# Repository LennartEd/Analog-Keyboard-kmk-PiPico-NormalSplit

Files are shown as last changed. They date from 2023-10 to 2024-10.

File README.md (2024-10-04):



# Analog-Keyboard-kmk-PiPico-NormalSplit
This is a fully analog keyboard using magnetic keys and hall sensors. I'm using a RP2040 but since it is KMK (circuitpython) based it should be compatible with other boards. I build a split keyboard, but any type form factor should work. 
This is my first experience with circuitpython so code might me wonky.

#TO-DO
- [ ] automatic callibration
- [ ] support all types of multiplexers (not just 16:1)
- [ ] fix mouse wheel only pressing every second turn

# PCB
**!DONT USE THE PCB PROVIDED!**
The PCB provided has some flaws that make it hard to work with.
**I would recommend making your own PCB and using mine as a template.**
In the future i might create v2 template that fixes the flaws.
Also as LCSC didn't have the LEDs in stock, I build mine without them. So there is no guaranty that I did the LED wiring correctly. I did however test the code with the onboard led of the RP2040, so the code should work.

### Flaws with v1
- Horizontal encoder has the wrong footprint (gnd is not in the middle)
- dont solder MCU daughter board onto PCB directly
- bigger pads for hand soldering
- more mounting holes
- if possible 2 layer PCB for cost saving

### Parts
|Description | Part | LCSC |
|:---| --- |:---|
| Hall sensor| HX6659ISO-B | C495742		|
| Multiplexer| CD74HC4067M96 | C496123		|
| TRRS jack  | PJ-3220-5A	 | C707251		|
| MCU		 | Waveshare RP2040-zero| --	|
| ~~Capacitor 100uF~~| ~~GRM21BR60J107ME15L~~| ~~C141660~~|
|(LED) |sk6812 mini-e  | C5149201 |

### Part notes
**Hall sensor:** 

**Multiplexer:** Currently any 16to1 Multiplexer should work (giving you 64 keys). If you are not hand soldering i recommend choosing a smaller sized one. Larger (32to1) should also work.

**MCU:** Any circuitpython compatible board should work. You just have to change the footprint on the PCB (which you should do anyway. See "Flaws with v1"

**TRRS jack:** 

**Capacitor:** Capacitors are not strictly necessary but improve resolution. ~~I tried a few and found that 100uF worked the best.~~ Use different sensor filters

#### How it works
The position of the magnet in the switch is red by the hall-effect sensor. Because the pi-pico only has 4 ADCs we need multiplexers to cycle between the sensors. 

# Code
To install the code connect your board and install circuitpython. Then copy the content of the "code" folder into the board. For editing the code you can use Thonny or any text editor.

### pins
To make life easier by not having to use "board.GP.." all the time, create (if not already present) a python file in lib/kmk/quickpin. Then add all the pins (see the other files for reference).
Now when imported with 
~~~
from kmk.quickpin.<boardTypeFolder>.<boardPins> import pinout as pins
~~~
into other files you can just use "pins[x]" to reference pins

### kb.py:
Here you define most variables for you specific board.

### Code.py

### hallCali.py

### analogio.py

# Case

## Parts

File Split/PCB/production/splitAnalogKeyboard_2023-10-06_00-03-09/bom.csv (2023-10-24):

Designator | Footprint | Quantity | Value | LCSC Part #
_22, _21, _20, _19, _18, _17, _16, _15, _14, _13, _12, _11, _10, _9, _8, _7, _6, _5, _4, _3, _2, | 634f0b0a-7a0d-49f3-8c6d-20ae2e3a1092 | 22
CN1 | AUDIO-TH_HOOYA_PJ-322 | 1 | PJ-322 | C2939185
H1_2, H1, H10_2, H10, H11_2, H11, H12_2, H12, H13_2, H13, H14_2, H14, H15_2, H15, H16_2, H16, H17_2, H17, H18_2, H18, H19_2, H19, H2_2, H2, H20_2, H20, H21_2, H21, H22_2, H22, H3_2, H3, H4_2, H4, H5_2, H5, H6_2, H6, H7_2, H7, H8_2, H8, H9_2, H9 | SOT-23-3_L2.9-W1.6-P1.90-LS2.8-BR | 44 | HX6659ISO-B | C495742
LED1_2, LED1, LED10_2, LED10, LED11_2, LED11, LED12_2, LED12, LED13_2, LED13, LED14_2, LED14, LED15_2, LED15, LED16_2, LED16, LED17_2, LED17, LED18_2, LED18, LED19_2, LED19, LED2_2, LED2, LED20_2, LED20, LED21_2, LED21, LED22_2, LED22, LED3_2, LED3, LED4_2, LED4, LED5_2, LED5, LED6_2, LED6, LED7_2, LED7, LED8_2, LED8, LED9_2, LED9 | LED-SMD_4P-L3.2-W2.8_SK6812MINI-EA | 44 | SK6812MINI-EA | C5378731
SW1, SW3 | MouseEncoder | 2 | ~
SW2 | SW-TH_EC11NXXXX | 1 | EC11N1520401 | C470703
U1_2, U1, U2_2, U2 | SOIC-24_L15.4-W7.5-P1.27-LS10.3-BL | 4 | CD74HC4067M96 | C496123
U3_2, U3 | RP2040-Zero-outer | 2 | RP2040-Zero

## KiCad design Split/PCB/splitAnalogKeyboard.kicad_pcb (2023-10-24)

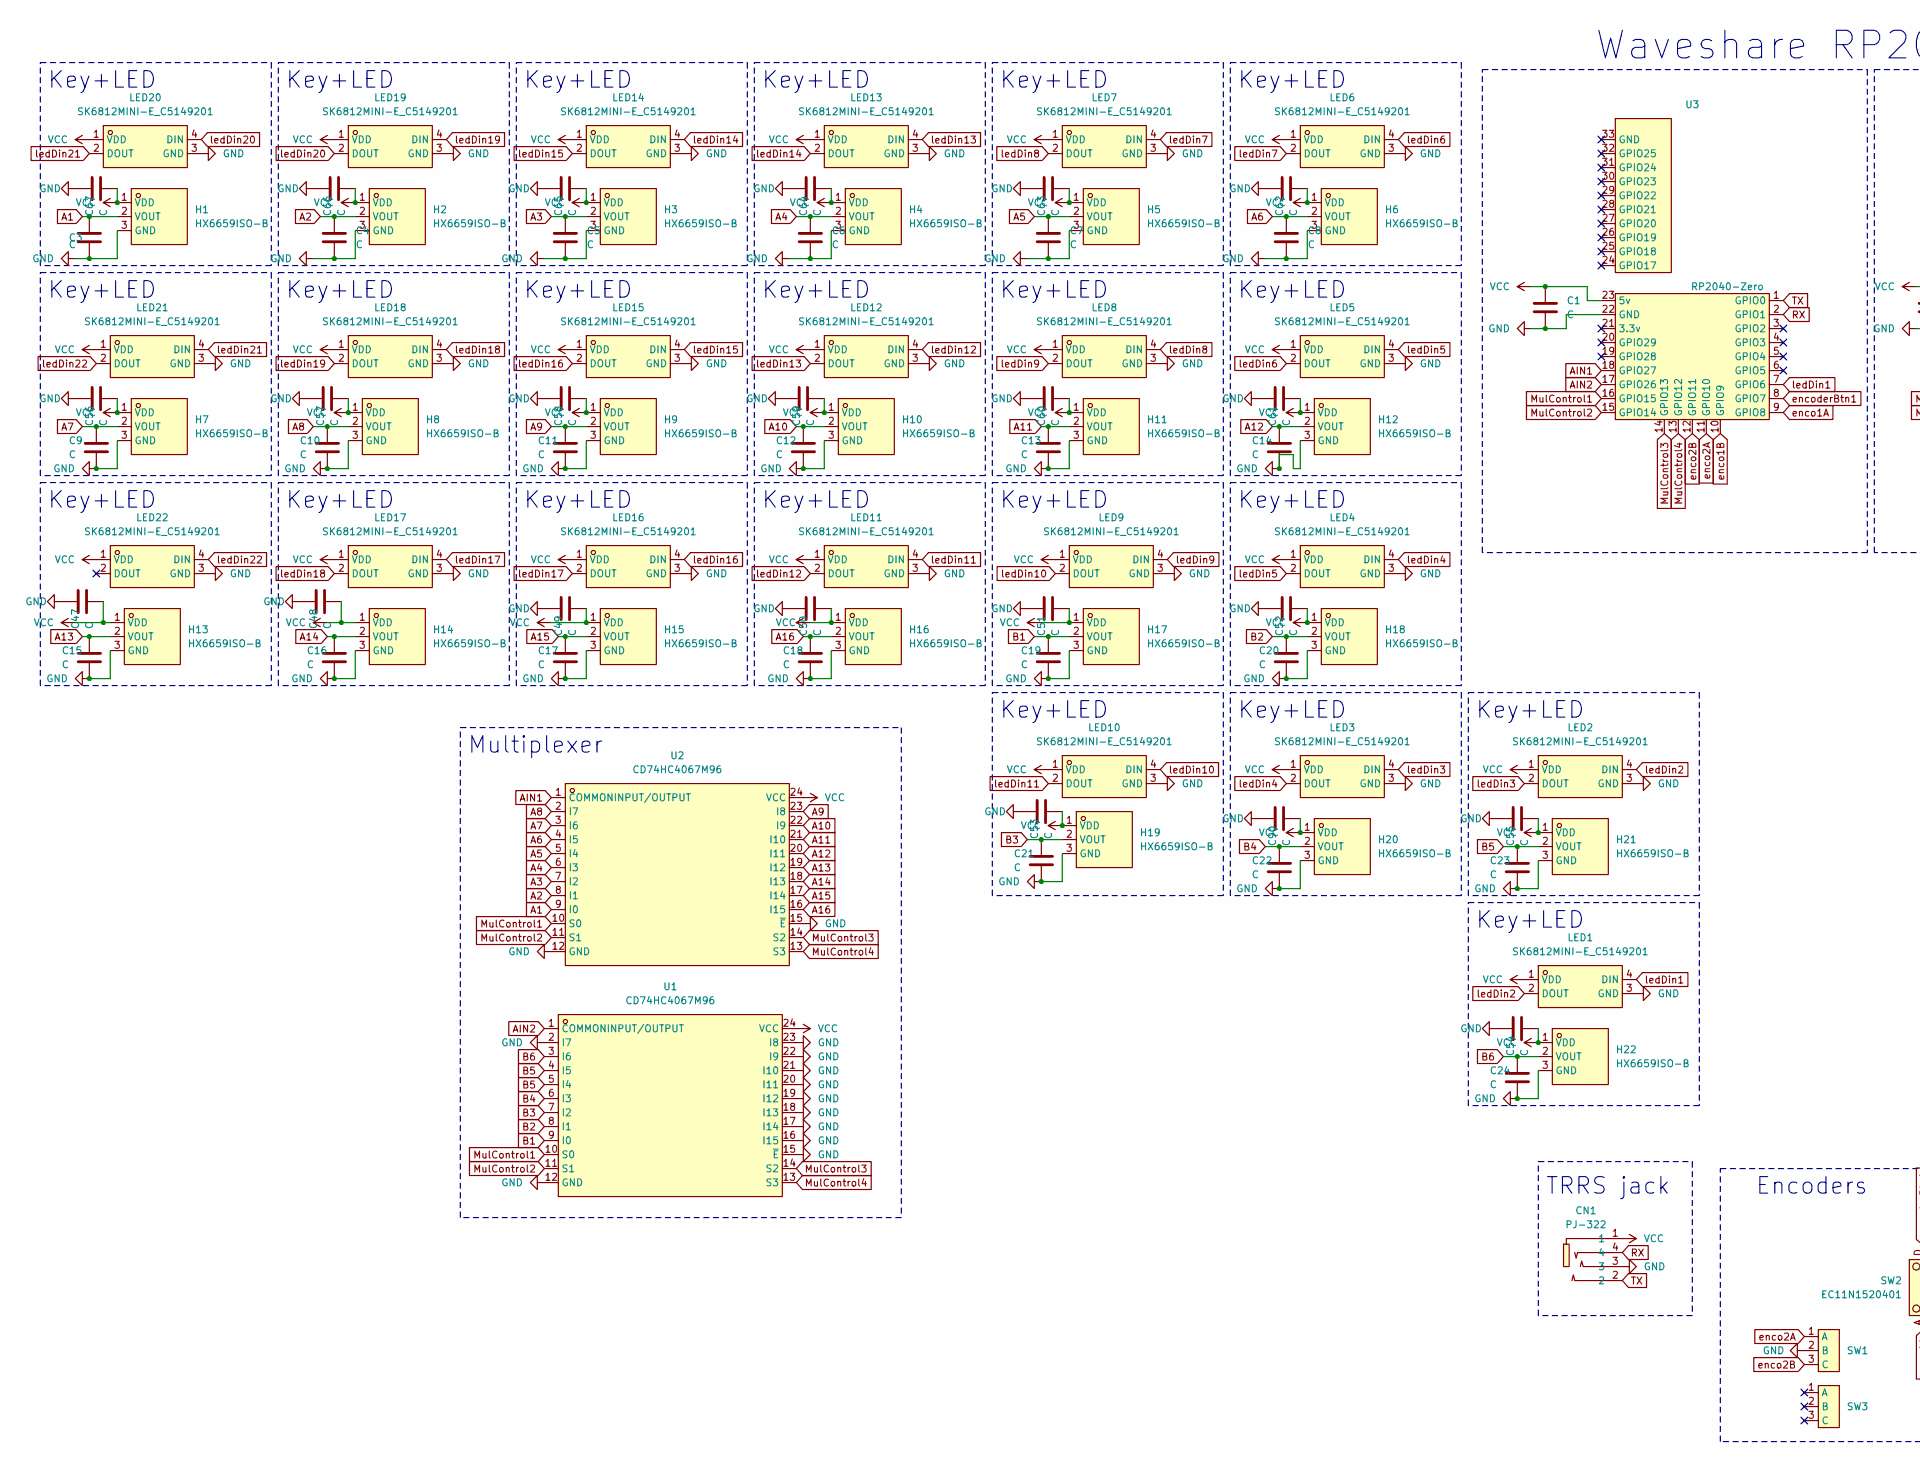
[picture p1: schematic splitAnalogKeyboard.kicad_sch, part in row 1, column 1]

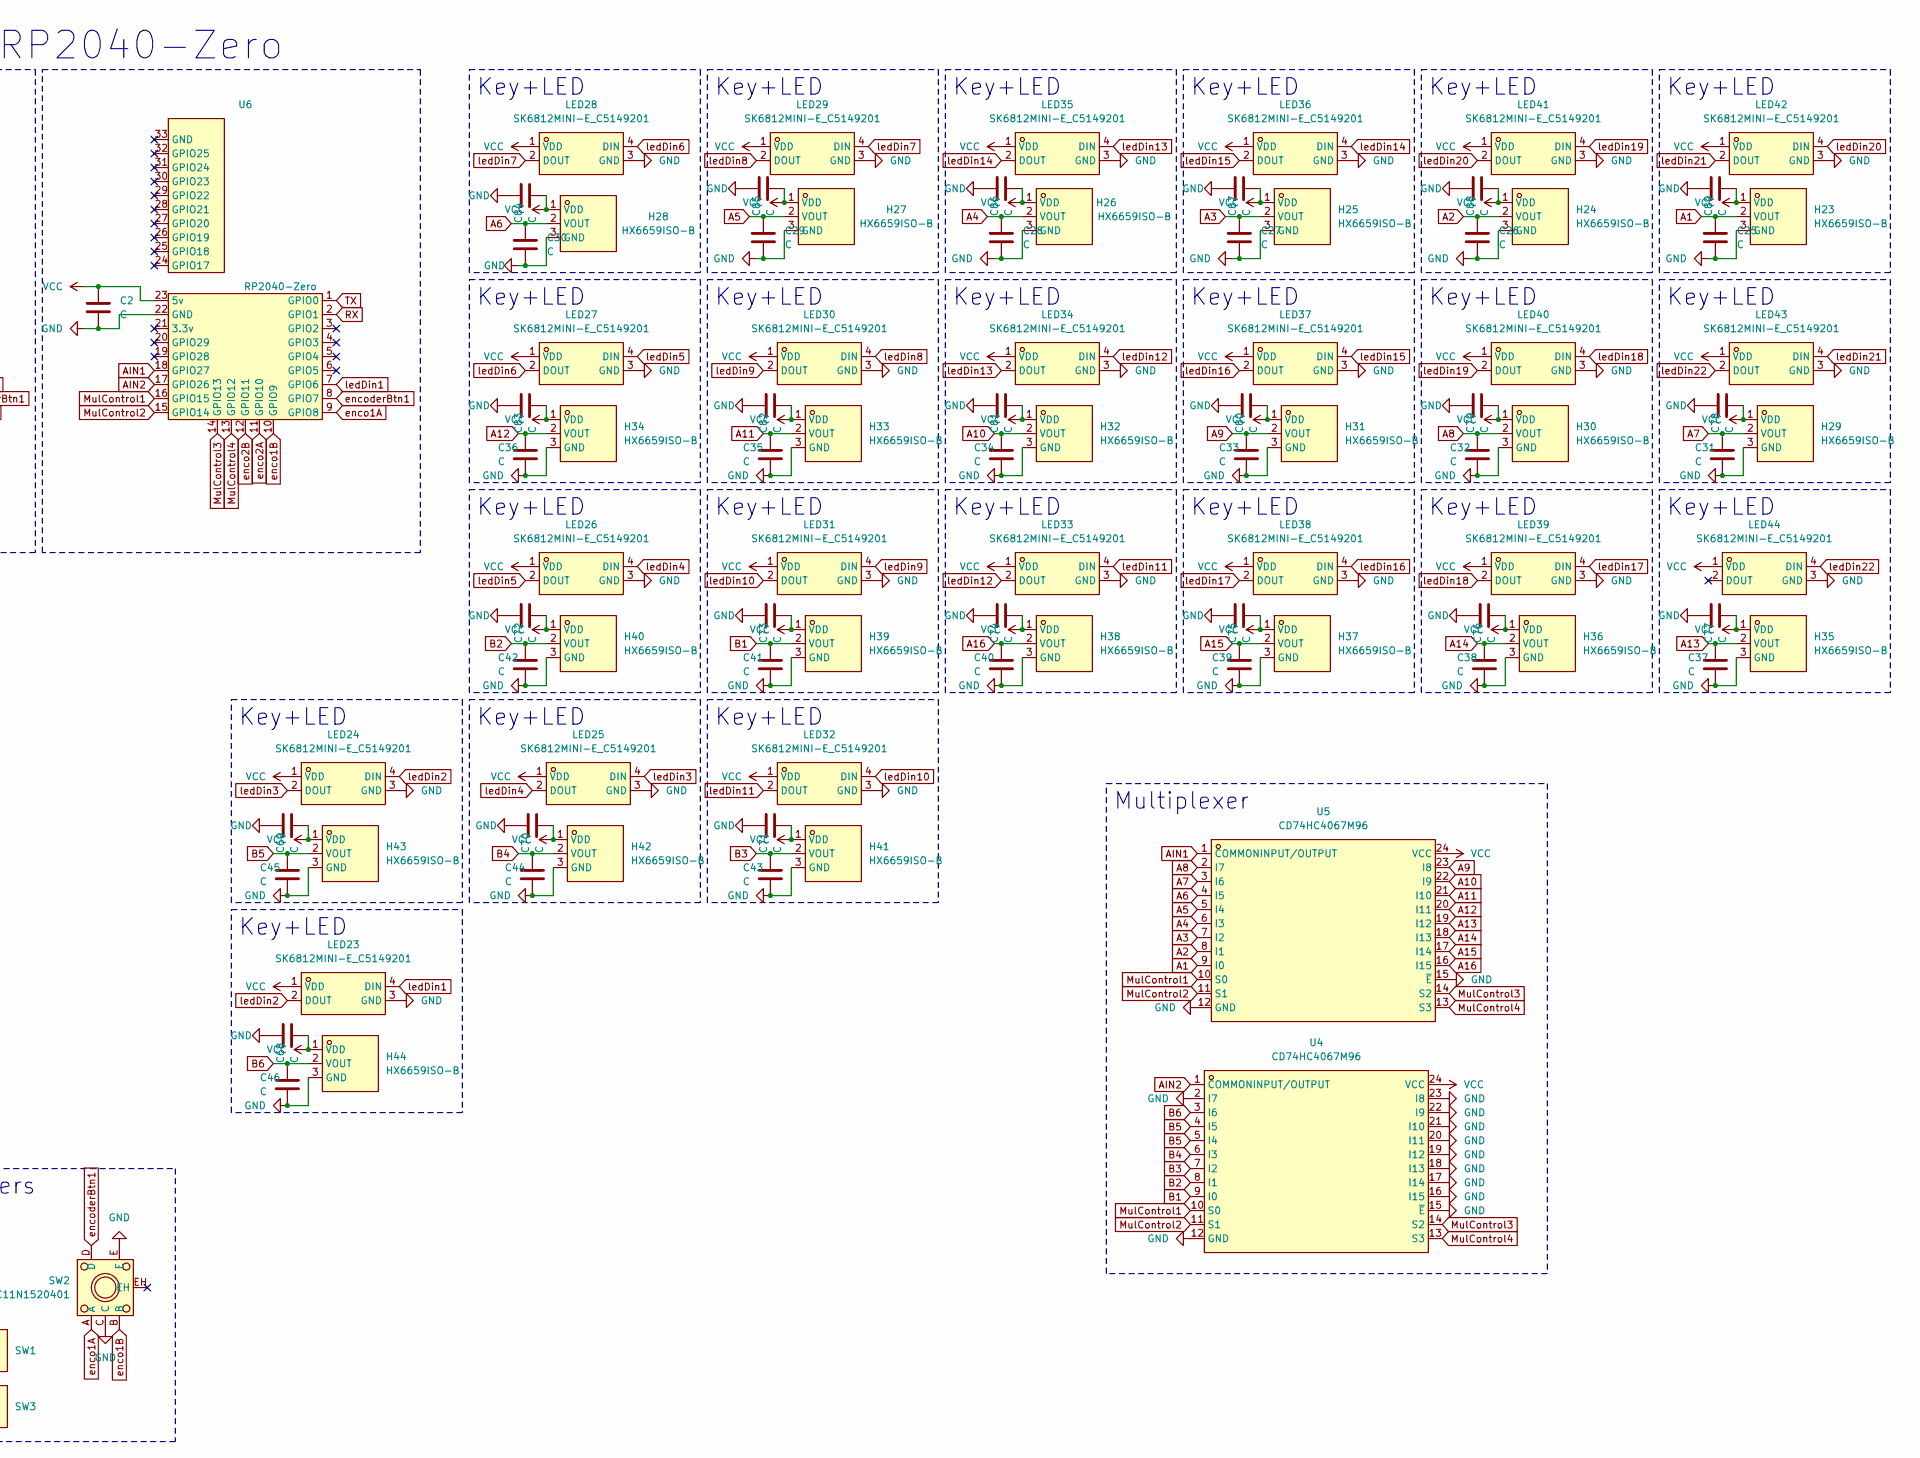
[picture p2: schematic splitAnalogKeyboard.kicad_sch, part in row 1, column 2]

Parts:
C1, C2, C3, C4, C5, C6, C7, C8, C9, C10, C11, C12, C13, C14, C15, C16, C17, C18, C19, C20, C21, C22, C23, C24, C25, C26, C27, C28, C29, C30, C31, C32, C33, C34, C35, C36, C37, C38, C39, C40, C41, C42, C43, C44, C45, C46, C47, C48, C49, C50, C51, C52, C53, C54, C55, C56, C57, C58, C59, C60, C61, C62, C63, C64, C65, C66, C67, C68, C69, C70, C71, C72, C73, C74, C75, C76, C77, C78, C79, C80, C81, C82, C83, C84, C85, C86, C87, C88, C89, C90: C; C_0805_2012Metric_Pad1.18x1.45mm_HandSolder
CN1: PJ-322; AUDIO-TH_HOOYA_PJ-322; LCSC Part C2939185
H1, H2, H3, H4, H5, H6, H7, H8, H9, H10, H11, H12, H13, H14, H15, H16, H17, H18, H19, H20, H21, H22, H23, H24, H25, H26, H27, H28, H29, H30, H31, H32, H33, H34, H35, H36, H37, H38, H39, H40, H41, H42, H43, H44: HX6659ISO-B; SOT-23-3_L2.9-W1.6-P1.90-LS2.8-BR; LCSC Part C495742
LED1, LED2, LED3, LED4, LED5, LED6, LED7, LED8, LED9, LED10, LED11, LED12, LED13, LED14, LED15, LED16, LED17, LED18, LED19, LED20, LED21, LED22, LED23, LED24, LED25, LED26, LED27, LED28, LED29, LED30, LED31, LED32, LED33, LED34, LED35, LED36, LED37, LED38, LED39, LED40, LED41, LED42, LED43, LED44: SK6812MINI-E_C5149201; LED-SMD_L3.2-W2.8-TR; LCSC Part C5149201
SW1, SW3: MouseEncoder
SW2: EC11N1520401; SW-TH_EC11NXXXX; LCSC Part C470703
U1, U2, U4, U5: CD74HC4067M96; SOIC-24_L15.4-W7.5-P1.27-LS10.3-BL; LCSC Part C496123
U3, U6: RP2040-Zero; RP2040-Zero-outer

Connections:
A1: C3.1, C25.1, H1.2 (VOUT), H23.2 (VOUT), U2.9 (I0), U5.9 (I0)
A2: C4.1, C26.1, H2.2 (VOUT), H24.2 (VOUT), U2.8 (I1), U5.8 (I1)
A3: C5.1, C27.1, H3.2 (VOUT), H25.2 (VOUT), U2.7 (I2), U5.7 (I2)
A4: C6.1, C28.1, H4.2 (VOUT), H26.2 (VOUT), U2.6 (I3), U5.6 (I3)
A5: C7.1, C29.1, H5.2 (VOUT), H27.2 (VOUT), U2.5 (I4), U5.5 (I4)
A6: C8.1, C30.1, H6.2 (VOUT), H28.2 (VOUT), U2.4 (I5), U5.4 (I5)
A7: C9.1, C31.1, H7.2 (VOUT), H29.2 (VOUT), U2.3 (I6), U5.3 (I6)
A8: C10.1, C32.1, H8.2 (VOUT), H30.2 (VOUT), U2.2 (I7), U5.2 (I7)
A9: C11.1, C33.1, H9.2 (VOUT), H31.2 (VOUT), U2.23 (I8), U5.23 (I8)
A10: C12.1, C34.1, H10.2 (VOUT), H32.2 (VOUT), U2.22 (I9), U5.22 (I9)
A11: C13.1, C35.1, H11.2 (VOUT), H33.2 (VOUT), U2.21 (I10), U5.21 (I10)
A12: C14.1, C36.1, H12.2 (VOUT), H34.2 (VOUT), U2.20 (I11), U5.20 (I11)
A13: C15.1, C37.1, H13.2 (VOUT), H35.2 (VOUT), U2.19 (I12), U5.19 (I12)
A14: C16.1, C38.1, H14.2 (VOUT), H36.2 (VOUT), U2.18 (I13), U5.18 (I13)
A15: C17.1, C39.1, H15.2 (VOUT), H37.2 (VOUT), U2.17 (I14), U5.17 (I14)
A16: C18.1, C40.1, H16.2 (VOUT), H38.2 (VOUT), U2.16 (I15), U5.16 (I15)
AIN1: U2.1 (COMMONINPUT/OUTPUT), U3.18 (GPIO27), U5.1 (COMMONINPUT/OUTPUT), U6.18 (GPIO27)
AIN2: U1.1 (COMMONINPUT/OUTPUT), U3.17 (GPIO26), U4.1 (COMMONINPUT/OUTPUT), U6.17 (GPIO26)
B1: C19.1, C41.1, H17.2 (VOUT), H39.2 (VOUT), U1.9 (I0), U4.9 (I0)
B2: C20.1, C42.1, H18.2 (VOUT), H40.2 (VOUT), U1.8 (I1), U4.8 (I1)
B3: C21.1, C43.1, H19.2 (VOUT), H41.2 (VOUT), U1.7 (I2), U4.7 (I2)
B4: C22.1, C44.1, H20.2 (VOUT), H42.2 (VOUT), U1.6 (I3), U4.6 (I3)
B5: C23.1, C45.1, H21.2 (VOUT), H43.2 (VOUT), U1.4 (I5), U1.5 (I4), U4.4 (I5), U4.5 (I4)
B6: C24.1, C46.1, H22.2 (VOUT), H44.2 (VOUT), U1.3 (I6), U4.3 (I6)
GND: C1.2, C2.2, C3.2, C4.2, C5.2, C6.2, C7.2, C8.2, C9.2, C10.2, C11.2, C12.2, C13.2, C14.2, C15.2, C16.2, C17.2, C18.2, C19.2, C20.2, C21.2, C22.2, C23.2, C24.2, C25.2, C26.2, C27.2, C28.2, C29.2, C30.2, C31.2, C32.2, C33.2, C34.2, C35.2, C36.2, C37.2, C38.2, C39.2, C40.2, C41.2, C42.2, C43.2, C44.2, C45.2, C46.2, C47.1, C48.1, C49.1, C50.1, C51.1, C52.1, C53.1, C54.1, C55.1, C56.1, C57.1, C58.1, C59.1, C60.1, C61.1, C62.1, C63.1, C64.1, C65.1, C66.1, C67.1, C68.1, C69.1, C70.1, C71.1, C72.1, C73.1, C74.1, C75.1, C76.1, C77.1, C78.1, C79.1, C80.1, C81.1, C82.1, C83.1, C84.1, C85.1, C86.1, C87.1, C88.1, C89.1, C90.1, CN1.3, H1.3 (GND), H2.3 (GND), H3.3 (GND), H4.3 (GND), H5.3 (GND), H6.3 (GND), H7.3 (GND), H8.3 (GND), H9.3 (GND), H10.3 (GND), H11.3 (GND), H12.3 (GND), H13.3 (GND), H14.3 (GND), H15.3 (GND), H16.3 (GND), H17.3 (GND), H18.3 (GND), H19.3 (GND), H20.3 (GND), H21.3 (GND), H22.3 (GND), H23.3 (GND), H24.3 (GND), H25.3 (GND), H26.3 (GND), H27.3 (GND), H28.3 (GND), H29.3 (GND), H30.3 (GND), H31.3 (GND), H32.3 (GND), H33.3 (GND), H34.3 (GND), H35.3 (GND), H36.3 (GND), H37.3 (GND), H38.3 (GND), H39.3 (GND), H40.3 (GND), H41.3 (GND), H42.3 (GND), H43.3 (GND), H44.3 (GND), LED1.3 (GND), LED2.3 (GND), LED3.3 (GND), LED4.3 (GND), LED5.3 (GND), LED6.3 (GND), LED7.3 (GND), LED8.3 (GND), LED9.3 (GND), LED10.3 (GND), LED11.3 (GND), LED12.3 (GND), LED13.3 (GND), LED14.3 (GND), LED15.3 (GND), LED16.3 (GND), LED17.3 (GND), LED18.3 (GND), LED19.3 (GND), LED20.3 (GND), LED21.3 (GND), LED22.3 (GND), LED23.3 (GND), LED24.3 (GND), LED25.3 (GND), LED26.3 (GND), LED27.3 (GND), LED28.3 (GND), LED29.3 (GND), LED30.3 (GND), LED31.3 (GND), LED32.3 (GND), LED33.3 (GND), LED34.3 (GND), LED35.3 (GND), LED36.3 (GND), LED37.3 (GND), LED38.3 (GND), LED39.3 (GND), LED40.3 (GND), LED41.3 (GND), LED42.3 (GND), LED43.3 (GND), LED44.3 (GND), SW1.2 (B), SW2.C, SW2.E, U1.2 (I7), U1.12 (GND), U1.15 (~E), U1.16 (I15), U1.17 (I14), U1.18 (I13), U1.19 (I12), U1.20 (I11), U1.21 (I10), U1.22 (I9), U1.23 (I8), U2.12 (GND), U2.15 (~E), U3.22 (GND), U4.2 (I7), U4.12 (GND), U4.15 (~E), U4.16 (I15), U4.17 (I14), U4.18 (I13), U4.19 (I12), U4.20 (I11), U4.21 (I10), U4.22 (I9), U4.23 (I8), U5.12 (GND), U5.15 (~E), U6.22 (GND)
MulControl1: U1.10 (S0), U2.10 (S0), U3.16 (GPIO15), U4.10 (S0), U5.10 (S0), U6.16 (GPIO15)
MulControl2: U1.11 (S1), U2.11 (S1), U3.15 (GPIO14), U4.11 (S1), U5.11 (S1), U6.15 (GPIO14)
MulControl3: U1.14 (S2), U2.14 (S2), U3.14 (GPIO13), U4.14 (S2), U5.14 (S2), U6.14 (GPIO13)
MulControl4: U1.13 (S3), U2.13 (S3), U3.13 (GPIO12), U4.13 (S3), U5.13 (S3), U6.13 (GPIO12)
RX: CN1.4, U3.2 (GPIO1), U6.2 (GPIO1)
TX: CN1.2, U3.1 (GPIO0), U6.1 (GPIO0)
VCC: C1.1, C2.1, C47.2, C48.2, C49.2, C50.2, C51.2, C52.2, C53.2, C54.2, C55.2, C56.2, C57.2, C58.2, C59.2, C60.2, C61.2, C62.2, C63.2, C64.2, C65.2, C66.2, C67.2, C68.2, C69.2, C70.2, C71.2, C72.2, C73.2, C74.2, C75.2, C76.2, C77.2, C78.2, C79.2, C80.2, C81.2, C82.2, C83.2, C84.2, C85.2, C86.2, C87.2, C88.2, C89.2, C90.2, CN1.1, H1.1 (VDD), H2.1 (VDD), H3.1 (VDD), H4.1 (VDD), H5.1 (VDD), H6.1 (VDD), H7.1 (VDD), H8.1 (VDD), H9.1 (VDD), H10.1 (VDD), H11.1 (VDD), H12.1 (VDD), H13.1 (VDD), H14.1 (VDD), H15.1 (VDD), H16.1 (VDD), H17.1 (VDD), H18.1 (VDD), H19.1 (VDD), H20.1 (VDD), H21.1 (VDD), H22.1 (VDD), H23.1 (VDD), H24.1 (VDD), H25.1 (VDD), H26.1 (VDD), H27.1 (VDD), H28.1 (VDD), H29.1 (VDD), H30.1 (VDD), H31.1 (VDD), H32.1 (VDD), H33.1 (VDD), H34.1 (VDD), H35.1 (VDD), H36.1 (VDD), H37.1 (VDD), H38.1 (VDD), H39.1 (VDD), H40.1 (VDD), H41.1 (VDD), H42.1 (VDD), H43.1 (VDD), H44.1 (VDD), LED1.1 (VDD), LED2.1 (VDD), LED3.1 (VDD), LED4.1 (VDD), LED5.1 (VDD), LED6.1 (VDD), LED7.1 (VDD), LED8.1 (VDD), LED9.1 (VDD), LED10.1 (VDD), LED11.1 (VDD), LED12.1 (VDD), LED13.1 (VDD), LED14.1 (VDD), LED15.1 (VDD), LED16.1 (VDD), LED17.1 (VDD), LED18.1 (VDD), LED19.1 (VDD), LED20.1 (VDD), LED21.1 (VDD), LED22.1 (VDD), LED23.1 (VDD), LED24.1 (VDD), LED25.1 (VDD), LED26.1 (VDD), LED27.1 (VDD), LED28.1 (VDD), LED29.1 (VDD), LED30.1 (VDD), LED31.1 (VDD), LED32.1 (VDD), LED33.1 (VDD), LED34.1 (VDD), LED35.1 (VDD), LED36.1 (VDD), LED37.1 (VDD), LED38.1 (VDD), LED39.1 (VDD), LED40.1 (VDD), LED41.1 (VDD), LED42.1 (VDD), LED43.1 (VDD), LED44.1 (VDD), U1.24 (VCC), U2.24 (VCC), U3.23 (5v), U4.24 (VCC), U5.24 (VCC), U6.23 (5v)
enco1A: SW2.A, U3.9 (GPIO8), U6.9 (GPIO8)
enco1B: SW2.B, U3.10 (GPIO9), U6.10 (GPIO9)
enco2A: SW1.1 (A), U3.11 (GPIO10), U6.11 (GPIO10)
enco2B: SW1.3 (C), U3.12 (GPIO11), U6.12 (GPIO11)
encoderBtn1: SW2.D, U3.8 (GPIO7), U6.8 (GPIO7)
ledDin1: LED1.4 (DIN), LED23.4 (DIN), U3.7 (GPIO6), U6.7 (GPIO6)
ledDin2: LED1.2 (DOUT), LED2.4 (DIN), LED23.2 (DOUT), LED24.4 (DIN)
ledDin3: LED2.2 (DOUT), LED3.4 (DIN), LED24.2 (DOUT), LED25.4 (DIN)
ledDin4: LED3.2 (DOUT), LED4.4 (DIN), LED25.2 (DOUT), LED26.4 (DIN)
ledDin5: LED4.2 (DOUT), LED5.4 (DIN), LED26.2 (DOUT), LED27.4 (DIN)
ledDin6: LED5.2 (DOUT), LED6.4 (DIN), LED27.2 (DOUT), LED28.4 (DIN)
ledDin7: LED6.2 (DOUT), LED7.4 (DIN), LED28.2 (DOUT), LED29.4 (DIN)
ledDin8: LED7.2 (DOUT), LED8.4 (DIN), LED29.2 (DOUT), LED30.4 (DIN)
ledDin9: LED8.2 (DOUT), LED9.4 (DIN), LED30.2 (DOUT), LED31.4 (DIN)
ledDin10: LED9.2 (DOUT), LED10.4 (DIN), LED31.2 (DOUT), LED32.4 (DIN)
ledDin11: LED10.2 (DOUT), LED11.4 (DIN), LED32.2 (DOUT), LED33.4 (DIN)
ledDin12: LED11.2 (DOUT), LED12.4 (DIN), LED33.2 (DOUT), LED34.4 (DIN)
ledDin13: LED12.2 (DOUT), LED13.4 (DIN), LED34.2 (DOUT), LED35.4 (DIN)
ledDin14: LED13.2 (DOUT), LED14.4 (DIN), LED35.2 (DOUT), LED36.4 (DIN)
ledDin15: LED14.2 (DOUT), LED15.4 (DIN), LED36.2 (DOUT), LED37.4 (DIN)
ledDin16: LED15.2 (DOUT), LED16.4 (DIN), LED37.2 (DOUT), LED38.4 (DIN)
ledDin17: LED16.2 (DOUT), LED17.4 (DIN), LED38.2 (DOUT), LED39.4 (DIN)
ledDin18: LED17.2 (DOUT), LED18.4 (DIN), LED39.2 (DOUT), LED40.4 (DIN)
ledDin19: LED18.2 (DOUT), LED19.4 (DIN), LED40.2 (DOUT), LED41.4 (DIN)
ledDin20: LED19.2 (DOUT), LED20.4 (DIN), LED41.2 (DOUT), LED42.4 (DIN)
ledDin21: LED20.2 (DOUT), LED21.4 (DIN), LED42.2 (DOUT), LED43.4 (DIN)
ledDin22: LED21.2 (DOUT), LED22.4 (DIN), LED43.2 (DOUT), LED44.4 (DIN)

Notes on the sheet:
Key+LED
Multiplexer
Encoders
Waveshare RP2040-Zero
TRRS jack

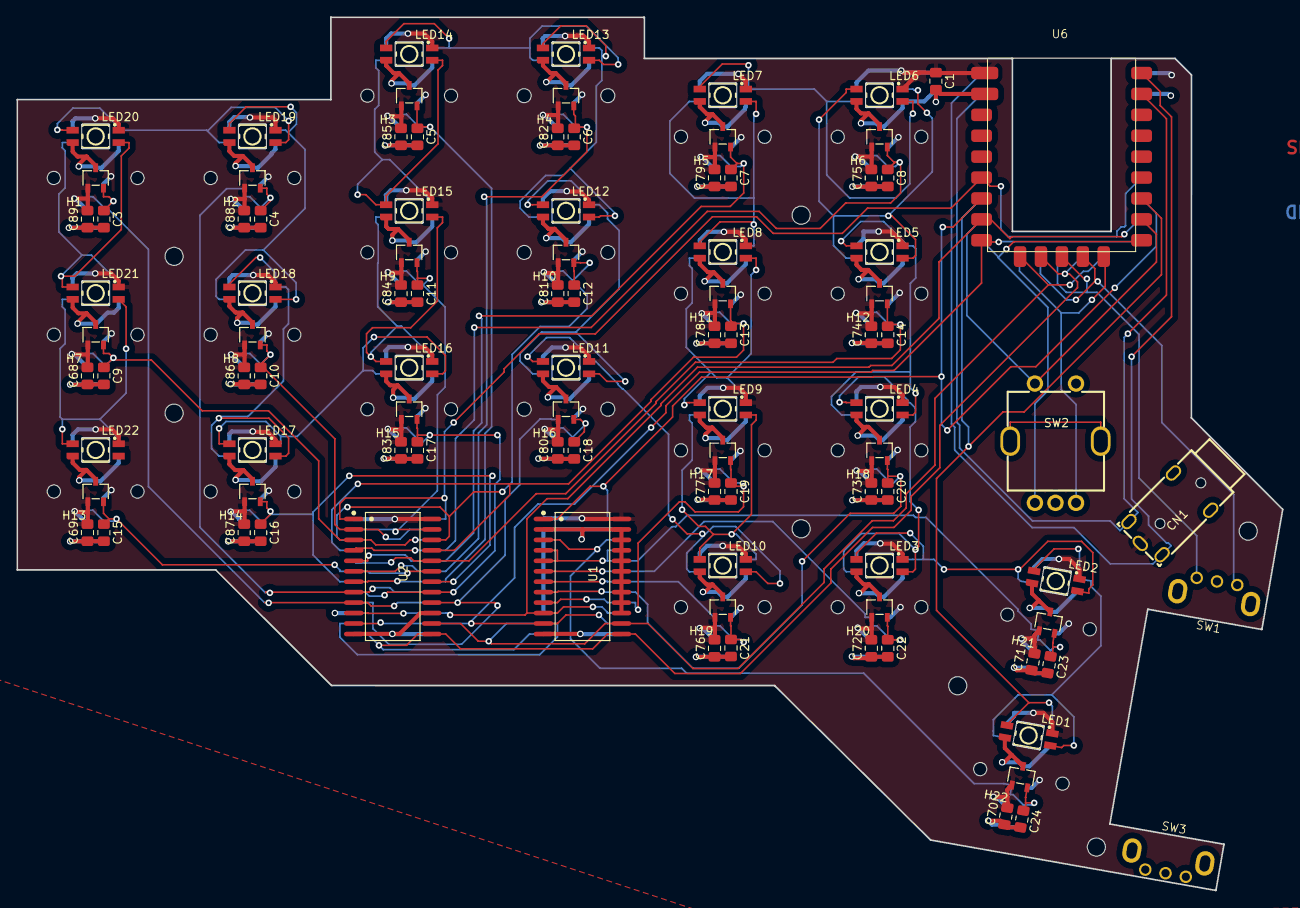
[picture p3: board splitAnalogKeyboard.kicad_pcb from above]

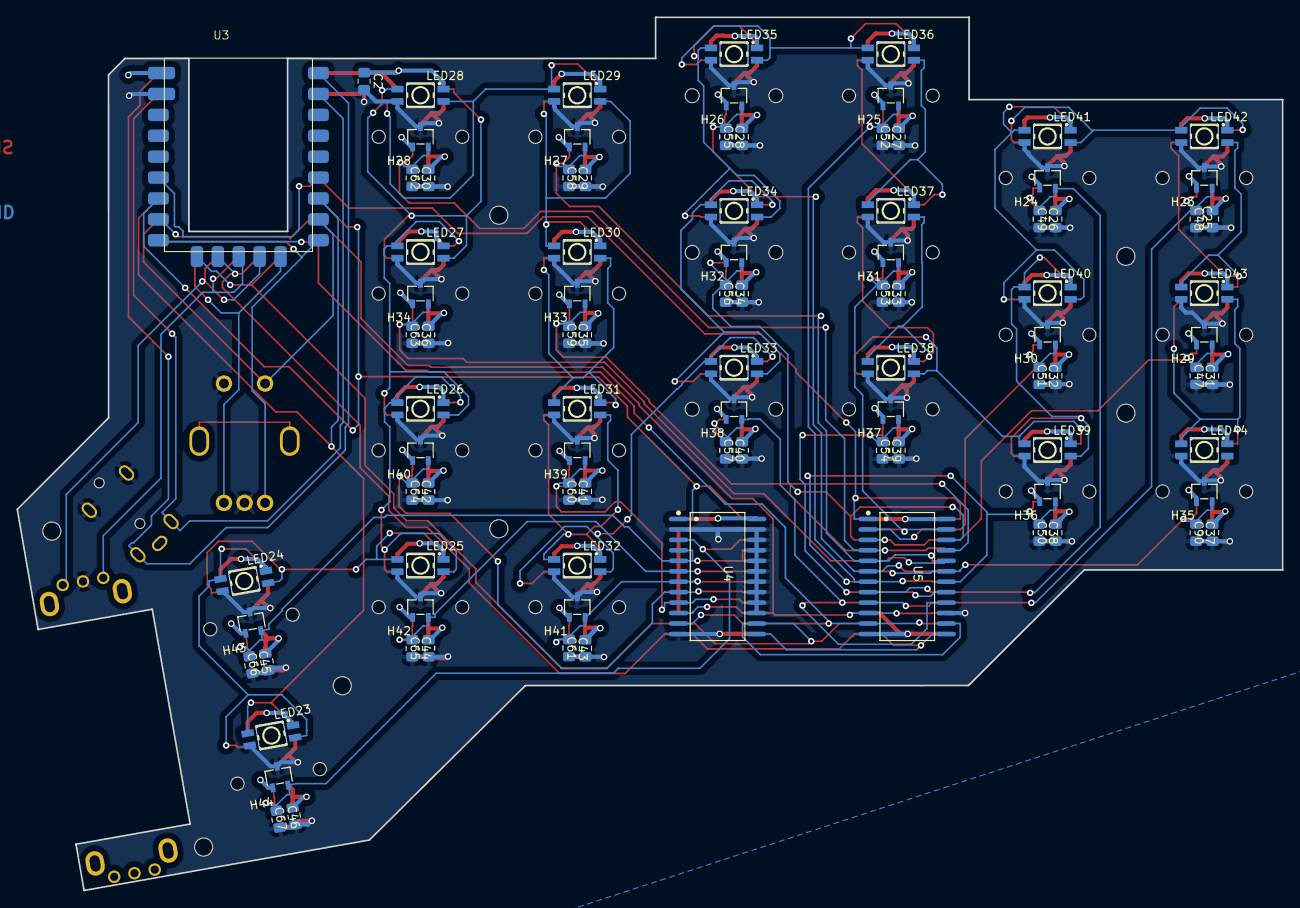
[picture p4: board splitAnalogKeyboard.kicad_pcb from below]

Board: 4 copper layers, 153.8 x 106.1 mm, 188 parts (92 on the bottom side), 59 nets.

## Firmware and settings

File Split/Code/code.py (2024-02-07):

print("start")
from kb import KMKKeyboard
from kmk.keys import KC
from kmk.modules.layers import Layers
from kmk.extensions.media_keys import MediaKeys
from kmk.modules.holdtap import HoldTap
from kmk.modules.mouse_keys import MouseKeys
from kmk.handlers.sequences import send_string, simple_key_sequence


keyboard = KMKKeyboard()
holdtap = HoldTap()

keyboard.modules.append(holdtap)
keyboard.modules.append(Layers())
keyboard.modules.append(MouseKeys())
keyboard.extensions.append(MediaKeys())


# Enable debugging: http://kmkfw.io/docs/debugging/ 
# keyboard.debug_enabled = True 
    

# Key aliases
xxxxx = KC.NO
_____ = KC.TRNS
T2 = KC.HT(KC.CAPS, KC.MO(1))
L0 = KC.TG(0)
L2 = KC.TG(2)
N2 = KC.HT(KC.TG(2), KC.MO(1))
N0 = KC.HT(KC.TG(0), KC.MO(1), prefer_hold=True, tap_interrupted=False, tap_time=None)
nW = simple_key_sequence((KC.LALT(KC.TAB),KC.MPLY)) #KC.MACRO_SLEEP_MS(1000)
pas = send_string("hi")

# Keymap 
# fmt: off bvb
keyboard.keymap = [
    [
       #Default qwerty
       #     |        |        |        |        |        |        | |        |        |        |        |        |        |        |
        KC.ESC,  KC.Q,    KC.W,    KC.E,    KC.R,    KC.T,                                     KC.Y,    KC.U,    KC.I,    KC.O,    KC.P,   KC.LGUI, 
        KC.TAB,  KC.A,    KC.S,    KC.D,    KC.F,    KC.G,                                     KC.H,    KC.J,    KC.K,    KC.L,    KC.SCLN, KC.DEL,  
        KC.BSPC,  KC.Z,    KC.X,    KC.C,    KC.V,   KC.B,                                    KC.N,    KC.M,    KC.COMM, KC.DOT,  KC.SLSH, KC.PSCR,  
                                            N2,KC.SPC,KC.LALT,KC.LCTL,                KC.ENT,KC.RCTL,KC.BSPC,   KC.LSFT,
                                                            
                                                                #encoder btn
                                                                nW,                   KC.MPLY,
                                                            
                                                            
        #Encoder 1 (horizontal) 
        KC.LEFT,    # left encoder Clock
        KC.RIGHT,    # left encoder counterClock
        KC.DOWN,    # right encoder Clock
        KC.UP,    # right encoder counterClock
        
        #Encoder 2 (vertical)
        KC.VOLD,    # left encoder Clock
        KC.VOLU,    # left encoder counterClock
        KC.MPRV,    # right encoder Clock
        KC.MNXT,    # right encoder counterClock
    ],
    [
       #Numbers
        _____,pas,KC.F1,KC.F2,KC.F3,KC.F4,                                 KC.F5,KC.F6,KC.F7,KC.F8,KC.F9,KC.F10, 
        _____,KC.N0,KC.N1,KC.N2,KC.N3,KC.N4,                                 KC.N5,KC.N6,KC.N7,KC.N8,KC.N9,KC.F11,  
        _____,xxxxx,xxxxx,xxxxx,xxxxx,KC.RALT,                                 KC.LEFT,KC.UP,KC.DOWN,KC.RIGHT,xxxxx,KC.F12,  
                                _____,_____,_____,  _____,       _____,_____,_____,_____,
                                                            
                                                #encoder btn
                                                    nW,                   KC.MPLY,
        #Encoder 1 (horizontal) 
        _____,    # left encoder Clock
        _____,    # left encoder counterClock
        _____,    # right encoder Clock
        _____,    # right encoder counterClock
        
        #Encoder 2 (vertical)
        _____,    # left encoder Clock
        _____,    # left encoder counterClock
        _____,    # right encoder Clock
        _____,    # right encoder counterClock
    ],
    [
       #Gaming 
        KC.ESC,  KC.Q,    KC.W,    KC.E,    KC.R,    KC.T,                                     KC.Y,    KC.U,    KC.I,    KC.O,    KC.P,   KC.LGUI, 
        KC.TAB,  KC.A,    KC.S,    KC.D,    KC.F,    KC.G,                                     KC.H,    KC.J,    KC.K,    KC.L,    KC.SCLN, KC.DEL,  
        KC.BSPC,  KC.Z,    KC.X,    KC.C,    KC.V,   KC.B,                                    KC.N,    KC.M,    KC.COMM, KC.DOT,  KC.SLSH, KC.PSCR,  
                                            N2,KC.SPC,KC.LALT,KC.LCTL,                KC.ENT,KC.RCTL,KC.BSPC,   KC.LSFT,
                                                            
                                                                #encoder btn
                                                                nW,                   KC.MPLY,
                                                            
                                                            
        #Encoder 1 (horizontal) 
        _____,    # left encoder Clock
        _____,    # left encoder counterClock
        _____,    # right encoder Clock
        _____,    # right encoder counterClock
        
        #Encoder 2 (vertical)
        _____,    # left encoder Clock
        _____,    # left encoder counterClock
        _____,    # right encoder Clock
        _____,    # right encoder counterClock
    ],
    
]
# fmt: on

if __name__ == "__main__":
    keyboard.go()
    

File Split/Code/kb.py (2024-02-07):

from kmk.quickpin.RP2040.YD_RP2040 import pinout as pins
#from kmk.quickpin.pro_micro.sparkfun_promicro_rp2040 import pinout as pins
from kmk.kmk_keyboard import KMKKeyboard as _KMKKeyboard
from kmk.scanners import DiodeOrientation
from kmk.modules.split import Split, SplitType, SplitSide
from kmk.scanners.keypad import KeysScanner
from kmk.scanners.analogio import AnalogScanner
from kmk.scanners.encoder import RotaryioEncoder
from kmk.scanners.encoder2 import RotaryioEncoder2

# from kmk.extensions.peg_rgb_matrix import Color

#LED order
led_positions = [
    19, 18, 13, 12,  6,  5,                  27, 28, 34, 35, 40, 41,
    20, 17, 14, 11,  7,  4,                  26, 29, 33, 36, 39, 42,
    21, 16, 15, 10,  8,  3,                  25, 30, 32, 37, 38, 43,
                     9,  2, 1, 0,    22, 23, 24, 31,
]

rgb_data = [
    [0, 0, 0], [0, 0, 0], [0, 0, 0], [0, 0, 0], [0, 0, 0], [0, 0, 0],                                                              [0, 0, 0], [0, 0, 0], [0, 0, 0], [0, 0, 0], [0, 0, 0], [0, 0, 0], 
    [0, 0, 0], [0, 0, 0], [0, 0, 0], [0, 0, 0], [0, 0, 0], [0, 0, 0],                                                              [0, 0, 0], [0, 0, 0], [0, 0, 0], [0, 0, 0], [0, 0, 0], [0, 0, 0], 
    [0, 0, 0], [0, 0, 0], [0, 0, 0], [0, 0, 0], [0, 0, 0], [0, 0, 0],                                                              [0, 0, 0], [0, 0, 0], [0, 0, 0], [0, 0, 0], [0, 0, 0], [0, 0, 0], 
                                                [0, 0, 0], [0, 0, 0], [0, 0, 0], [0, 25, 25],               [0, 25, 25],[0, 0, 0], [0, 0, 0], [0, 0, 0],
]

# Creates a tuple containing both LED position and RGB data
pos_rgb = [(x, y) for x, y in zip(led_positions, rgb_data)]


class KMKKeyboard(_KMKKeyboard):
    def __init__(
        self
    ):
        # create and register the scanner(s)
        self.matrix = [
            
            AnalogScanner(
                inPins = self.analogPins,
                outPins = self.outPins,
                multiNum = self.multiplexer,
                numOfKeys = self.numberOfKeys,
                analogAttrib = self.analogKeyAttribut
            ),
            
            KeysScanner(
                # require argument:
                pins=self.encoderBtnPins,
                # optional arguments with defaults:
                value_when_pressed=False,
                pull=True,
                interval=0.02,  # Debounce time in floating point seconds
                max_events=64
            ),
            RotaryioEncoder(
                pin_a=self.encoder1_a,
                pin_b=self.encoder1_b,
                divisor=2,
            ),
            RotaryioEncoder2(
                pin_a=self.encoder2_a,
                pin_b=self.encoder2_b,
                divisor=2,
            ),
            
             
        ]

        # Split code:
        split = Split(
            split_flip=True,  # If both halves are the same, but flipped, set this True
            split_side=None,  # Sets if this is to SplitSide.LEFT or SplitSide.RIGHT, or use EE hands
            split_type=SplitType.UART,  # Defaults to UART
            uart_interval=1,  # Sets the uarts delay. Lower numbers draw more power
            data_pin=self.rx,  # The primary data pin to talk to the secondary device with
            data_pin2=self.tx,  # Second uart pin to allow 2 way communication
            uart_flip = False,
            use_pio=True,  # Use RP2040 PIO implementation of UART. Required if you want to use other pins than RX/TX
        )
        self.modules.append(split)
        
        self.setup_rgb()
    
    analogPins = (      #analog pins from which values are read
    pins[27],pins[26],
    )
    outPins = (pins[15],pins[14],pins[13],pins[12]) #pins to control the multiplexers
    
    multiplexer = 16 #number of input pins of the multiplexer
    
    numberOfKeys = 22  #number of analog keys (per side if its split)
    
    analogKeyAttribut = [ #choose per key modes and values (positive means threshold negativ means rapid trigger 
        [
            2,2,2,2,2,2,
            2,2,2,2,2,2,
            2,2,2,2,2,2,
                  2,2,2,
                      2,
            
            0,0,0,0,0,
            
            2,2,2,2,2,2,
            2,2,2,2,2,2,
            2,2,2,2,2,2,
                  2,2,2,
                      2,
        ],
        [
            2,2,2,2,2,2,
            2,2,2,2,2,2,
            2,2,2,2,2,2,
                  2,2,2,
                      2,
            
            0,0,0,0,0,0,
            
            2,2,2,2,2,2,
            2,2,2,2,2,2,
            2,2,2,2,2,2,
                  2,2,2,
                      2,
        ],
        [
            2,2,2,-0.2,2,2,
            2,2,-0.2,-0.2,-0.2,2,
            2,2,2,2,2,2,
                  2,2,2,
                      2,
            
            0,0,0,0,0,0,
            
            2,2,2,2,2,2,
            2,2,2,2,2,2,
            2,2,2,2,2,2,
                  2,2,2,
                      2,
        ],
    ]
    
    encoderBtnPins = [pins[7]] #pins for the encoder buttons
    
    #encoder1 pins
    encoder1_a = pins[11] 
    encoder1_b = pins[10]
    #encoder2 pins
    encoder2_a = pins[9]
    encoder2_b = pins[8]
    
    rx = pins[1]
    tx = pins[0]
    rgb_pixel_pin = pins[16] #LED pin

    # Basic RGB code:
    def basic_rgb(self, pixels):
        from kmk.extensions.RGB import RGB

        rgb = RGB(
            pixel_pin=self.rgb_pixel_pin,
            num_pixels=pixels,
            val_limit=50,
            hue_default=0,
            sat_default=100,
            val_default=20,
        )
        
        self.extensions.append(rgb)

    # PEG_RGB code (per key RGB):
    def peg_rgb(self, led_display):
        from kmk.extensions.peg_rgb_matrix import Rgb_matrix, Rgb_matrix_data

        rgb_ext = Rgb_matrix(
            ledDisplay=led_display,
            split=True,
            rightSide=False,
            disable_auto_write=True,
        )
        self.extensions.append(rgb_ext)

    # "Calculate" the position data
    def trim_pos(self, pos_rgb, cut):
        cut_pos = [p for (p, d) in pos_rgb if p not in cut]
        old_to_new = {old: new for new, old in enumerate(sorted(cut_pos))}
        return [old_to_new[p] for p in cut_pos]

    # Setup for peg_rgb or basic_rgb:
    def setup_rgb(self):
            self.brightness_limit = 0.1
            # Exctract and trim the position data from the pos_rgb tuple 
            self.led_key_pos = self.trim_pos(pos_rgb, [])
            # Return the number of items in the exctracted and trimmed data from above:
            self.num_pixels = len(led_positions)
            # Pass the specifig [R, G, B] data via 'led_display' into peg_rgb():
            #self.peg_rgb(self.trim_display(pos_rgb, []))
            self.peg_rgb(rgb_data)
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

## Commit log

2023-10-24 test pcb
    [bom.csv, designators.csv, positions.csv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]
2023-11-10 uart flip false,attrib change
    [code.py, kb.py]
2023-12-15 rapidTrigger changes to not get stuck
    [code.py, hallCali.py, kb.py]
2024-03-08 horizontal encoder error
2024-10-04 Dont use my filters
